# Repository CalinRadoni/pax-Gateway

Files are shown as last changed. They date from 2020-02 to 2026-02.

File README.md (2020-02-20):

# ESP32 RFM69HCW / RFM95/96/97/98(W) Gateway

The purpose of this gateway is to either:

- connect a RFM69-based network to Wi-Fi
- connect a LoRa&trade; transceiver to Wi-Fi

The gateway was designed for power efficiency without sacrificing functionality.

**Status:** (*this is work in progress !*)

## Features

- the core is a ESP32-WROOM-32x Wi-Fi+BT+BLE module
- RFM69HCW or RFM95/96/97/98(W) module
- Li-Ion / Li-Polymer battery charger
- Li-Ion / Li-Polymer backup battery with 18650 or 14500 sockets
- high efficiency synchronous buck converter
- supply voltage supervisor
- 4 LEDs for status
- humidity and temperature sensor
- placeholder for ATSHA204A, ATECC508A or ATECC608A IC
- (*optional*) boot mode selection using DTR and RTS signal

## Software

The code dedicated to this board is not yet built.

## Development Environment

Operating system is [Debian](https://www.debian.org/)

Tools:

- [KiCad EDA](http://kicad-pcb.org/)
- [Visual Studio Code](https://code.visualstudio.com/)
- [Espressif IoT Development Framework](https://github.com/espressif/esp-idf)
- [Git](https://git-scm.com/)
- [GIMP](https://www.gimp.org/)
- [Inkscape](https://inkscape.org/en/)

## Versions

### Version 1

- *Fab* files are moved to the Fab-v1 directory
- The PCBs from SeeedStudio arrived
- Most components are sourced
- I should build some boards
- I should start to write some software

## License

The software and documentation are released under the [GNU GPLv3](http://www.gnu.org/licenses/gpl-3.0.html) License. See the __LICENSE-GPLv3.txt__ file.

The hardware schematics are licensed under a [Creative Commons Attribution-ShareAlike 4.0 International License](http://creativecommons.org/licenses/by-sa/4.0/).
See the __LICENSE-CC-BY-SA-4.0.txt__ file.

## About RFM modules

### RFM69

From it's datasheet:

*The RFM69HCW is a transceiver module capable of operation over a wide frequency range, including the 315,433,868 and 915MHz license-free ISM (Industry Scientific and Medical) frequency bands.*

*All major RF communication parameters are programmable and most of them can be dynamically set. The RFM69HCW offers the unique advantage of programmable narrow-band and wide- band communication modes.*

*The RFM69HCW is optimized for low power consumption while offering high RF output power and channelized operation. Compliance ETSI and FCC regulations.*

### RFM95/96/97/98(W)

From it's datasheet:

*The RFM95/96/97/98(W) incorporates the LoRa TM spread spectrum modem which is capable of achieving significantly longer range than existing systems based on FSK or OOK modulation.*

*[...] Another benefit of the spread modulation is that each spreading factor is orthogonal - thus multiple transmitted signals can occupy the same channel without interfering. This also permits simple coexistence with existing FSK based systems.*

*Standard GFSK, FSK, OOK, and GMSK modulation is also provided to allow compatibility with existing systems or standards such as wireless MBUS and IEEE 802.15.4g.*

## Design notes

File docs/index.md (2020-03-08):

---
layout: page
title: "Documentation for pax-Gateway"
description: "pax-Gateway: Documentation about usage, hardware and software"
---

right now this page is for testing the integration with GitHub Pages

## Title 2

### Title 3

#### Title 4

text *text* **text**

* aaa
* bbb
* [pax-devices](https://github.com/CalinRadoni/pax-devices)

```c++
/**
This file is part of pax-devices (https://github.com/CalinRadoni/pax-devices)
*/

#include "freertos/FreeRTOS.h"
#include "freertos/task.h"

const char* TAG = "Init";

extern "C" {

    void app_main()
    {
        simpleOTA.CheckApplicationImage();

        esp_err_t err = board.Initialize();
        if (err != ESP_OK) {
            ESP_LOGE(TAG, "Initialization failed !");
            board.DoNothingForever();
        }

        // ... nothing more, just highlighting test

    }
}
```

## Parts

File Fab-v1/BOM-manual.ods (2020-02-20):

Reference | Value | Footprint | notes | source | variant | characteristics | manufacturer | package | part-number | Qty | 2
C1,C2,C5,C6,C22,C26,C30,C32 | 100nF | CalinGeneric:C0805HS |  |  |  | 100 nF / 50V / X7R | Samsung | 0805 | CL21B104KBCNNNC | 8 | 16
C41 | 100nF | CalinGeneric:C0805HS |  |  | Sensor | 100 nF / 50V / X7R | Samsung | 0805 | CL21B104KBCNNNC | 1 | 2
C3,C10,C20,C21,C31 | 10uF | CalinGeneric:C0805HS |  |  |  | 10 µF / 6,3 V | Samsung | 0805 | CL21B106KQQNNNE | 5 | 10
C23 | 10uF/10V/1mOhm | CalinGeneric:C0805HS |  |  |  | 10 µF / 10 V / X5R / ESR: 1 mΩ | Taiyo Yuden | 0805 | EMK212BJ106KG-T | 1 | 2
C24 | 22uF/6.3V/1mOhm | CalinGeneric:C0805HS |  |  |  | 22 µF / 6.3 V / X5R / ESR: 1 mΩ | Taiyo Yuden | 0805 | JMK212BBJ226MGHT | 1 | 2
C25 | 100pF | CalinGeneric:C0805HS |  |  |  | 100pF / 50V / X7R | Wurth Electronics | 0805 | 885012207080 | 1 | 2
D1 | LED | CalinGeneric:LED0805HS |  |  |  | Green ? Blue ? |  | 0805 |  | 1 | 2
D10-D13 | LED | CalinGeneric:LED0805HS |  |  |  | Green ? Yellow-green ? |  | 0805 |  | 4 | 8
D21 | B340AE-13 | CalinGeneric:SMA-HS |  |  |  | 3A schottky rectifier | Diodes | SMA | B340AE-13 | 1 | 2
D29 | LED Green | CalinGeneric:LED0805HS |  |  | test | Green ? ... ? |  |  |  | 1 | 2
J23 | s18650 | CalinConnectors:KEYS-1043 |  |  | 18650 |  | Keystone | * | KEYS1043 | 1 | 2
J30 | AntSMA | CalinConnectors:SMA-90 |  |  |  | RF2-49B-T-00-50-G-HDW or RF2-03E-T-00-50-G | Adam Tech | * | RF2-49B-T-00-50-G-HDW | 1 | 2
L21 | 2.2uH | CalinGeneric:ASPI-0530HI |  |  |  |  | Abracon Corporation |  | ASPI-0530HI-2R2M-T2 | 1 | 2
Q20 | IRLML2244 | CalinGeneric:SOT-23-GSD-HS |  |  |  | * | International Rectifier | SOT23-3 | IRLML2244TRPbF | 1 | 2
Q40, Q41 | BC817 | CalinGeneric:SOT-23 |  |  |  | BC817-40 | Diodes | SOT-23 | BC817-40 | 2 | 4
R1,R25,R26,R40,R41 | 10k | CalinGeneric:R0805HS |  |  |  | 10k | Vishay | 0805 | CRCW080510K0FKEA | 5 | 10
R2, R29 | 330 | CalinGeneric:R0805HS |  |  |  | 330 | Vishay | 0805 | CRCW0805330RFKTABC | 2 | 4
R3,R4,R20 | 2k2 | CalinGeneric:R0805HS |  |  |  | 2k2 | Panasonic | 0805 | ERJ-6ENF2201V | 3 | 6
R10 - R13 | 100 | CalinGeneric:R0805HS |  |  |  | 100 1% | Panasonic | 0805 | ERJ-6ENF1000V | 4 | 8
R22, R23 | 2M | CalinGeneric:R0805HS |  | Mouser |  | 2M 1% | Panasonic | 0805 | ERJ-6ENF2004V | 2 | 4
R27 | 442k 1% | CalinGeneric:R0805HS |  | Mouser |  | 442k 1% | Panasonic | 0805 | ERJ-6ENF4423V | 1 | 2
R28 | 100k 1% | CalinGeneric:R0805HS |  | Mouser |  | 100k 1% | Panasonic | 0805 | ERJ-6ENF1003V | 1 | 2
SYM10 – SYM13 | LightPipe | CalinGeneric:SLP3-xxx-150-x |  |  |  | LightPipe | BIVAR | SLP3-XXX-XXX-X | SLP3-150-150-F | 4 | 8
U1 | ESP-WROOM-32 | CalinGeneric:ESP-WROOM-32-HandSolder |  |  |  | * | Espressif | * | ESP32-WROOM-32 | 1 | 2
U20 | IRM-10-5 | CalinGeneric:IRM222A |  |  |  |  | Mean Well | 222A | IRM-10-5 | 1 | 2
U21 | MCP73832T-2ACI | CalinGeneric:SOT-23-5-HS |  |  |  |  | Microchip | SOT23-5 | MCP73832T-2ACI | 1 | 2
U22 | BD49K35 | CalinGeneric:SOT-23-HS |  |  |  |  | ROHM Semiconductor | SSOP3 (SOT23-3) | BD49K37G-TL | 1 | 2
U23 | TLV62569DBV | CalinGeneric:SOT-23-5-HS |  |  |  |  | Texas Instrumnets | SOT23-5 | TLV62569DBV | 1 | 2
U24 | TLV379IDBV | CalinGeneric:SOT-23-5-HS |  |  |  |  | Texas Instruments | SOT23-5 | TLV379IDBV | 1 | 2
U30 | RFM9x | CalinGeneric:RFM69HCW |  |  |  | * | HOPERF | * | RFM69HCW | 1 | 2
U41 | HDC1080DMB | CalinGeneric:WSON6-TI-HDC-HS |  |  | Sensor |  | Texas Instruments | WSON6 | HDC1080DMB | 1 | 2
Box |  |  |  | TME |  |  | Gainta |  | G738 or G706
J1 | ph_1x2 | CalinConnectors:Pin_Header_Straight_1x02 | DNP |  | test |  |  |  |  | 1 | 2
J2 | ph_1x2 | CalinConnectors:Pin_Header_Straight_1x02 | DNP |  | test |  |  |  |  | 1 | 2
J21 | ph_1x2 | CalinConnectors:Pin_Header_Straight_1x02 | DNP |  | test |  |  |  |  | 1 | 2
J40 | ph_1x2 | CalinConnectors:Pin_Header_Straight_1x02 |  |  |  |  |  |  |  | 1 | 2
J3 | ph_1x3 | CalinConnectors:Pin_Header_Straight_1x03_Cyan |  |  |  |  |  |  |  | 1 | 2
J4 | ph_1x4 | CalinConnectors:Pin_Header_Straight_1x04 |  |  |  |  |  |  |  | 1 | 2
J5 | ph_1x4 | CalinConnectors:Pin_Header_Straight_1x04 |  |  |  |  |  |  |  | 1 | 2
J7 | ph_1x4 | CalinConnectors:Pin_Header_Straight_1x04 | DNP |  | test |  |  |  |  | 1 | 2
J6 | ph_1x3 | CalinConnectors:Pin_Header_Straight_1x03_Yellow |  |  |  |  |  |  |  | 1 | 2
J8 | ph_1x6 | CalinConnectors:Pin_Header_Straight_1x06 |  |  |  | * | * | * | * | 1 | 2
J20 | 220V~ | CalinConnectors:THT_Pins_Big_1x3 | DNP |  | pcb |  |  |  |  | 1 | 2
J22 | s14500 | CalinConnectors:BattHolder-AA-PCB |  |  | 14500 |  |  |  |  | 1 | 2

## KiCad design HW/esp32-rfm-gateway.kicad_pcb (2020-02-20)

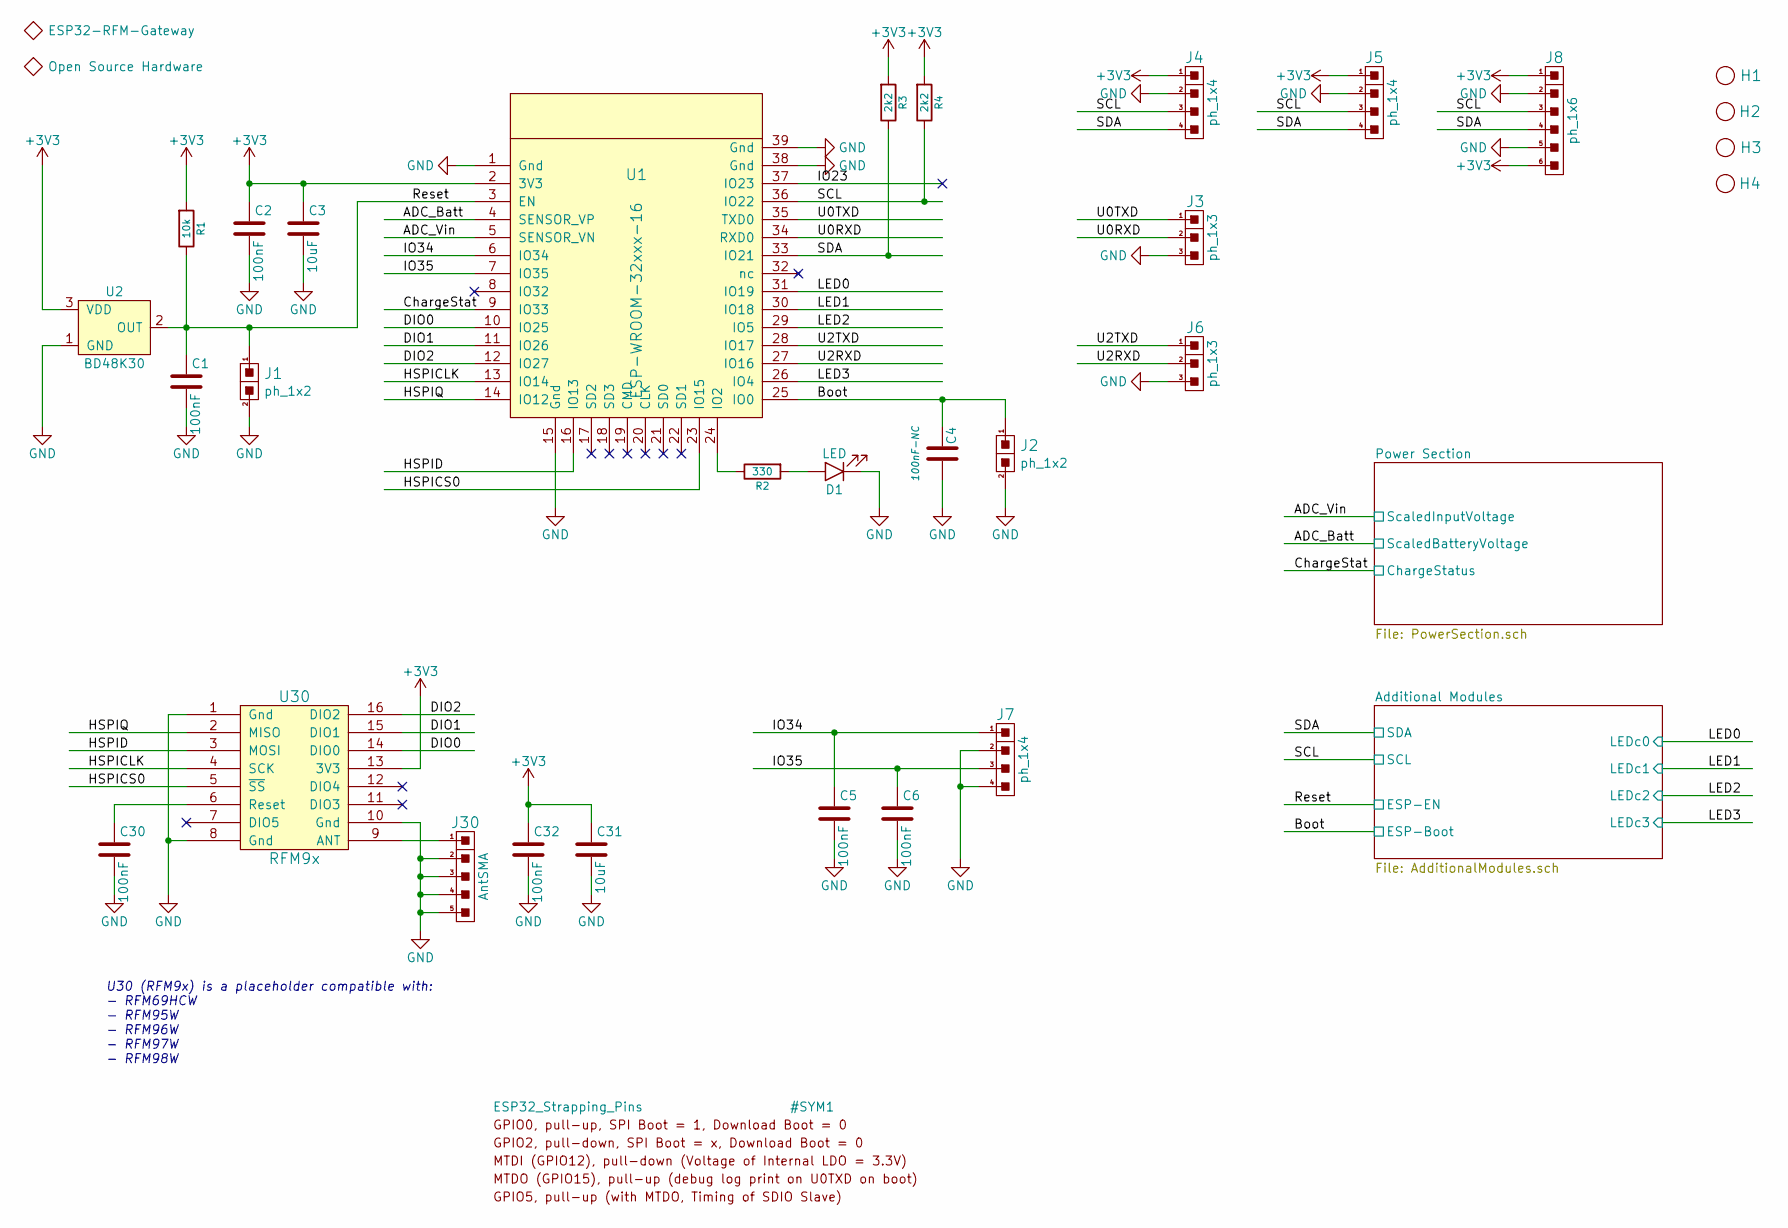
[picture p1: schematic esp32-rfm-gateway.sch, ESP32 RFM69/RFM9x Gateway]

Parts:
C1, C2, C5, C6, C30, C32: 100nF; C0805HS; part-number CL21B104KBCNNNC
C3, C31: 10uF; C0805HS; part-number CL21B106KQQNNNE
C4: 100nF-NC; C0805HS; part-number DNP
D1: LED; LED0805HS
H1, H2, H3, H4: Hole; HoleNPT-M2.5
J1, J2: ph_1x2; Pin_Header_Straight_1x02
J3: ph_1x3; Pin_Header_Straight_1x03_Cyan
J4, J5, J7: ph_1x4; Pin_Header_Straight_1x04
J6: ph_1x3; Pin_Header_Straight_1x03_Yellow
J8: ph_1x6; Pin_Header_Straight_1x06; part-number *
J30: AntSMA; SMA-90; part-number RF2-49B-T-00-50-G-HDW
R1: 10k; R0805HS; part-number CRCW080510K0FKEA
R2: 330; R0805HS; part-number CRCW0805330RFKTABC
R3, R4: 2k2; R0805HS; part-number ERJ-6ENF2201V
SYM2: Open Source Hardware; OSHW-Logo_SilkS; part-number DNP
SYM5: ESP32-RFM-Gateway; ValueAsText; part-number DNP
U1: ESP-WROOM-32xxx-16; ESP-WROOM-32-HandSolder; part-number ESP32-WROOM-32D-16
U2: BD48K30; SOT-23-HS; part-number BD48K30G-TL
U30: RFM9x; RFM69HCW; part-number RFM69HCW

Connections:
+3V3: C2.1, C3.1, C31.1, C32.1, J4.1, J5.1, J8.1, J8.6, R1.1, R3.1, R4.1, U1.2 (3V3), U2.3 (VDD), U30.13 (3V3); also elsewhere on the board
/ADC_Batt: U1.4 (SENSOR_VP); also elsewhere on the board
/ADC_Vin: U1.5 (SENSOR_VN); also elsewhere on the board
/Boot: C4.1, J2.1, U1.25 (IO0); also elsewhere on the board
/ChargeStat: U1.9 (IO33); also elsewhere on the board
/DIO0: U1.10 (IO25), U30.14 (DIO0)
/DIO1: U1.11 (IO26), U30.15 (DIO1)
/DIO2: U1.12 (IO27), U30.16 (DIO2)
/HSPICLK: U1.13 (IO14), U30.4 (SCK)
/HSPICS0: U1.23 (IO15), U30.5 (~SS)
/HSPID: U1.16 (IO13), U30.3 (MOSI)
/HSPIQ: U1.14 (IO12), U30.2 (MISO)
/IO34: C5.1, J7.1, U1.6 (IO34)
/IO35: C6.1, J7.3, U1.7 (IO35)
/LED0: U1.31 (IO19); also elsewhere on the board
/LED1: U1.30 (IO18); also elsewhere on the board
/LED2: U1.29 (IO5); also elsewhere on the board
/LED3: U1.26 (IO4); also elsewhere on the board
/Reset: C1.1, J1.1, R1.2, U1.3 (EN), U2.2 (OUT); also elsewhere on the board
/SCL: J4.3, J5.3, J8.3, R4.2, U1.36 (IO22); also elsewhere on the board
/SDA: J4.4, J5.4, J8.4, R3.2, U1.33 (IO21); also elsewhere on the board
/U0RXD: J3.2, U1.34 (RXD0)
/U0TXD: J3.1, U1.35 (TXD0)
/U2RXD: J6.2, U1.27 (IO16)
/U2TXD: J6.1, U1.28 (IO17)
GND: C1.2, C2.2, C3.2, C4.2, C5.2, C6.2, C30.2, C31.2, C32.2, D1.K, J1.2, J2.2, J3.3, J4.2, J5.2, J6.3, J7.2, J7.4, J8.2, J8.5, J30.2, J30.3, J30.4, J30.5, U1.1 (Gnd), U1.15 (Gnd), U1.38 (Gnd), U1.39 (Gnd), U2.1 (GND), U30.1 (Gnd), U30.8 (Gnd), U30.10 (Gnd); also elsewhere on the board
unnamed: C30.1, U30.6 (Reset)
unnamed: D1.A, R2.1
unnamed: J30.1, U30.9 (ANT)
unnamed: R2.2, U1.24 (IO2)

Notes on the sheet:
U30 (RFM9x) is a placeholder compatible with: - RFM69HCW - RFM95W - RFM96W - RFM97W - RFM98W

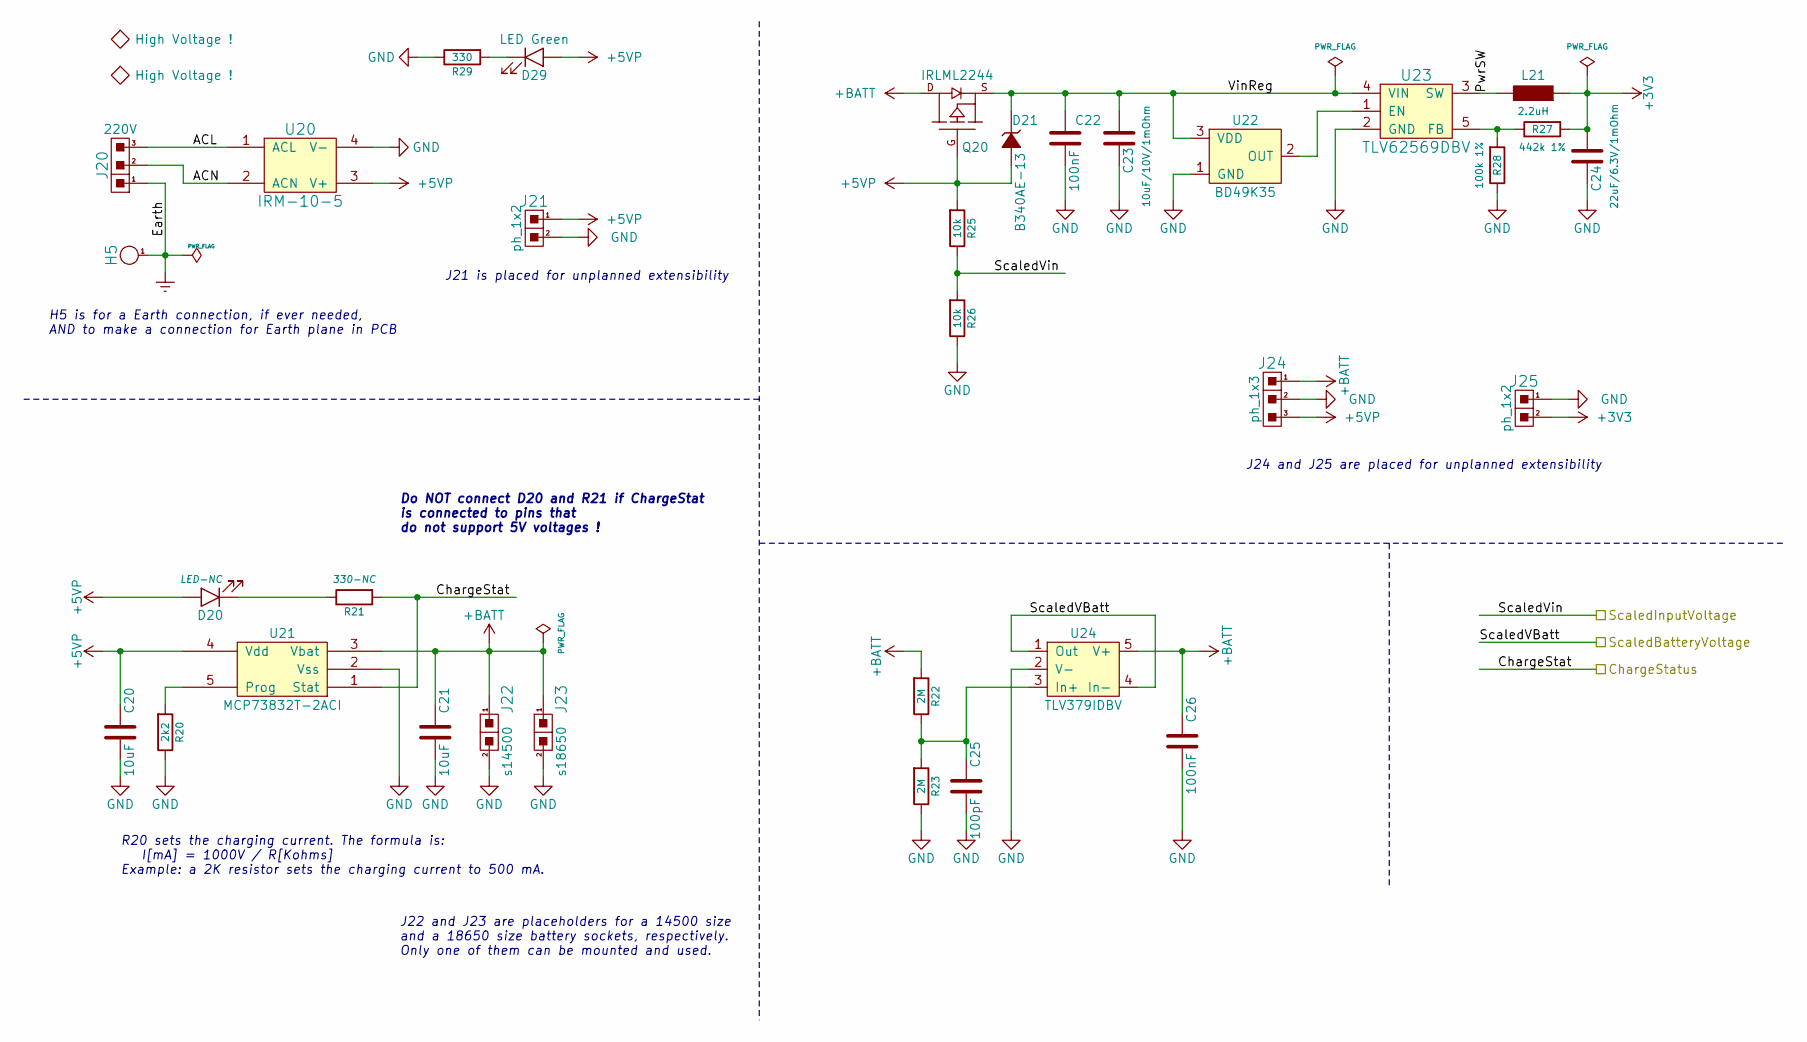
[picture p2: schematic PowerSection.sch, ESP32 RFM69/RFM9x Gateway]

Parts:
C20, C21: 10uF; C0805HS; part-number CL21B106KQQNNNE
C22, C26: 100nF; C0805HS; part-number CL21B104KBCNNNC
C23: 10uF/10V/1mOhm; C0805HS; part-number EMK212BJ106KG-T
C24: 22uF/6.3V/1mOhm; C0805HS; part-number JMK212BBJ226MGHT
C25: 100pF; C0805HS; part-number 885012207080
D20: LED-NC; LED0805HS; part-number DNP
D21: B340AE-13; SMA-HS; part-number B340AE-13
D29: LED Green; LED0805HS
H5: HolePlated; SMD_Pins_Big_1x1
J20: 220V~; THT_Pins_Big_1x3
J21: ph_1x2; Pin_Header_Straight_1x02
J22: s14500; BattHolder-AA-PCB
J23: s18650; KEYS-1043; part-number KEYS1043
J24: ph_1x3; Pin_Header_Angled_1x03
J25: ph_1x2; Pin_Header_Angled_1x02
L21: 2.2uH; ASPI-0530HI; part-number ASPI-0530HI-2R2M-T2
Q20: IRLML2244; SOT-23-GSD-HS; part-number IRLML2244TRPbF
R20: 2k2; R0805HS; part-number ERJ-6ENF2201V
R21: 330-NC; R0805HS; part-number DNP
R22, R23: 2M; R0805HS; part-number ERJ-6ENF2004V
R25, R26: 10k; R0805HS; part-number CRCW080510K0FKEA
R27: 442k 1%; R0805HS; part-number ERJ-6ENF4423V
R28: 100k 1%; R0805HS; part-number ERJ-6ENF1003V
R29: 330; R0805HS; part-number CRCW0805330RFKTABC
SYM3, SYM4: High Voltage !; Symbol_HighVoltage_SilkS; part-number DNP
U20: IRM-10-5; IRM222A; part-number IRM-10-5
U21: MCP73832T-2ACI; SOT-23-5-HS; part-number MCP73832T-2ACI
U22: BD49K35; SOT-23-HS; part-number BD49K37G-TL
U23: TLV62569DBV; SOT-23-5-HS; part-number TLV62569DBV
U24: TLV379IDBV; SOT-23-5-HS; part-number TLV379IDBV

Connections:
+3V3: C24.1, J25.2, L21.1, R27.1; also elsewhere on the board
+5VP: C20.1, D20.A, D21.2 (A), D29.A, J21.1, J24.3, Q20.G, R25.1, U20.3 (V+), U21.4 (Vdd)
+BATT: C21.1, C26.1, J22.1, J23.1, J24.1, Q20.D, R22.1, U21.3 (Vbat), U24.5 (V+)
/ADC_Batt: U24.1 (Out), U24.4 (In-); also elsewhere on the board
/ADC_Vin: R25.2, R26.1; also elsewhere on the board
/ChargeStat: R21.1, U21.1 (Stat); also elsewhere on the board
/Power Section/ACL: J20.3, U20.1 (ACL)
/Power Section/ACN: J20.2, U20.2 (ACN)
/Power Section/PwrSW: L21.2, U23.3 (SW)
/Power Section/VinReg: C22.1, C23.1, D21.1 (K), Q20.S, U22.3 (VDD), U23.4 (VIN)
Earth: H5.1, J20.1
GND: C20.2, C21.2, C22.2, C23.2, C24.2, C25.2, C26.2, J21.2, J22.2, J23.2, J24.2, J25.1, R20.2, R23.2, R26.2, R28.2, R29.2, U20.4 (V-), U21.2 (Vss), U22.1 (GND), U23.2 (GND), U24.2 (V-); also elsewhere on the board
unnamed: C25.1, R22.2, R23.1, U24.3 (In+)
unnamed: D20.K, R21.2
unnamed: D29.K, R29.1
unnamed: R20.1, U21.5 (Prog)
unnamed: R27.2, R28.1, U23.5 (FB)
unnamed: U22.2 (OUT), U23.1 (EN)

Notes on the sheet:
J24 and J25 are placed for unplanned extensibility
J21 is placed for unplanned extensibility
R20 sets the charging current. The formula is: I[mA] = 1000V / R[Kohms] Example: a 2K resistor sets the charging current to 500 mA.
J22 and J23 are placeholders for a 14500 size and a 18650 size battery sockets, respectively. Only one of them can be mounted and used.
H5 is for a Earth connection, if ever needed, AND to make a connection for Earth plane in PCB
Do NOT connect D20 and R21 if ChargeStat is connected to pins that do not support 5V voltages !

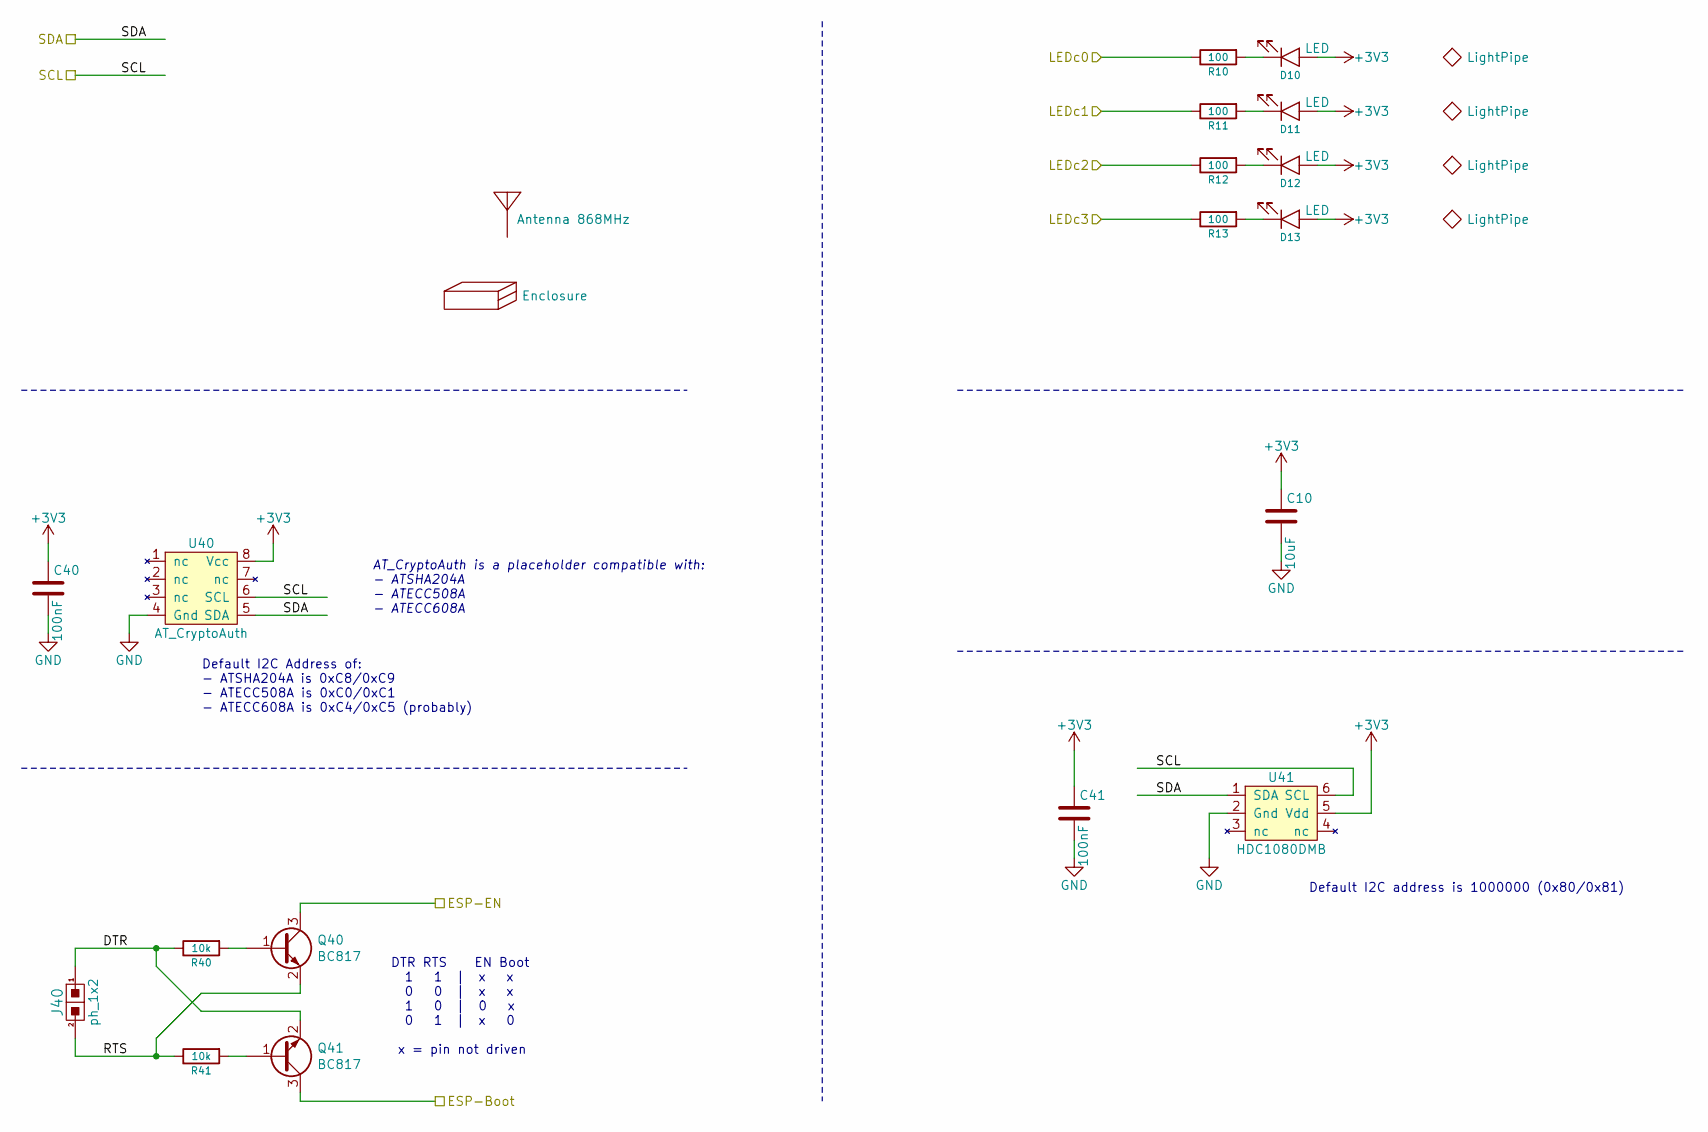
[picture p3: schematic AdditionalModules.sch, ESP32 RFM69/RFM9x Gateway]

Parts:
C10: 10uF; C0805HS; part-number CL21B106KQQNNNE
C40, C41: 100nF; C0805HS; part-number CL21B104KBCNNNC
D10, D11, D12, D13: LED; LED0805HS
J40: ph_1x2; Pin_Header_Straight_1x02
Q40, Q41: BC817; SOT-23; part-number BC817-40
R10, R11, R12, R13: 100; R0805HS; part-number ERJ-6ENF1000V
R40, R41: 10k; R0805HS; part-number CRCW080510K0FKEA
SYM6: Antenna 868MHz; VirtualFootprint; part-number 868M-ANT410
SYM9: Enclosure; VirtualFootprint; part-number Gainta G706
SYM10, SYM11, SYM12, SYM13: LightPipe; SLP3-xxx-150-x; part-number SLP3-150-150-F
U40: AT_CryptoAuth; SOIC-8-HS; part-number ATSHA204A/ATECC508A/ATECC608A-SSHDA
U41: HDC1080DMB; WSON6-TI-HDC-HS; part-number HDC1080DMB

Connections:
+3V3: C10.1, C40.1, C41.1, D10.A, D11.A, D12.A, D13.A, U40.8 (Vcc), U41.5 (Vdd); also elsewhere on the board
/Additional Modules/DTR: J40.1, Q41.2 (E), R40.2
/Additional Modules/RTS: J40.2, Q40.2 (E), R41.2
/Boot: Q41.3 (C); also elsewhere on the board
/LED0: R10.2; also elsewhere on the board
/LED1: R11.2; also elsewhere on the board
/LED2: R12.2; also elsewhere on the board
/LED3: R13.2; also elsewhere on the board
/Reset: Q40.3 (C); also elsewhere on the board
/SCL: U40.6 (SCL), U41.6 (SCL); also elsewhere on the board
/SDA: U40.5 (SDA), U41.1 (SDA); also elsewhere on the board
GND: C10.2, C40.2, C41.2, U40.4 (Gnd), U41.2 (Gnd); also elsewhere on the board
unnamed: D10.K, R10.1
unnamed: D11.K, R11.1
unnamed: D12.K, R12.1
unnamed: D13.K, R13.1
unnamed: Q40.1 (B), R40.1
unnamed: Q41.1 (B), R41.1

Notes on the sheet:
AT_CryptoAuth is a placeholder compatible with: - ATSHA204A - ATECC508A - ATECC608A
DTR RTS EN Boot 1 1 | x x 0 0 | x x 1 0 | 0 x 0 1 | x 0 x = pin not driven
Default I2C Address of: - ATSHA204A is 0xC8/0xC9 - ATECC508A is 0xC0/0xC1 - ATECC608A is 0xC4/0xC5 (probably)
Default I2C address is 1000000 (0x80/0x81)

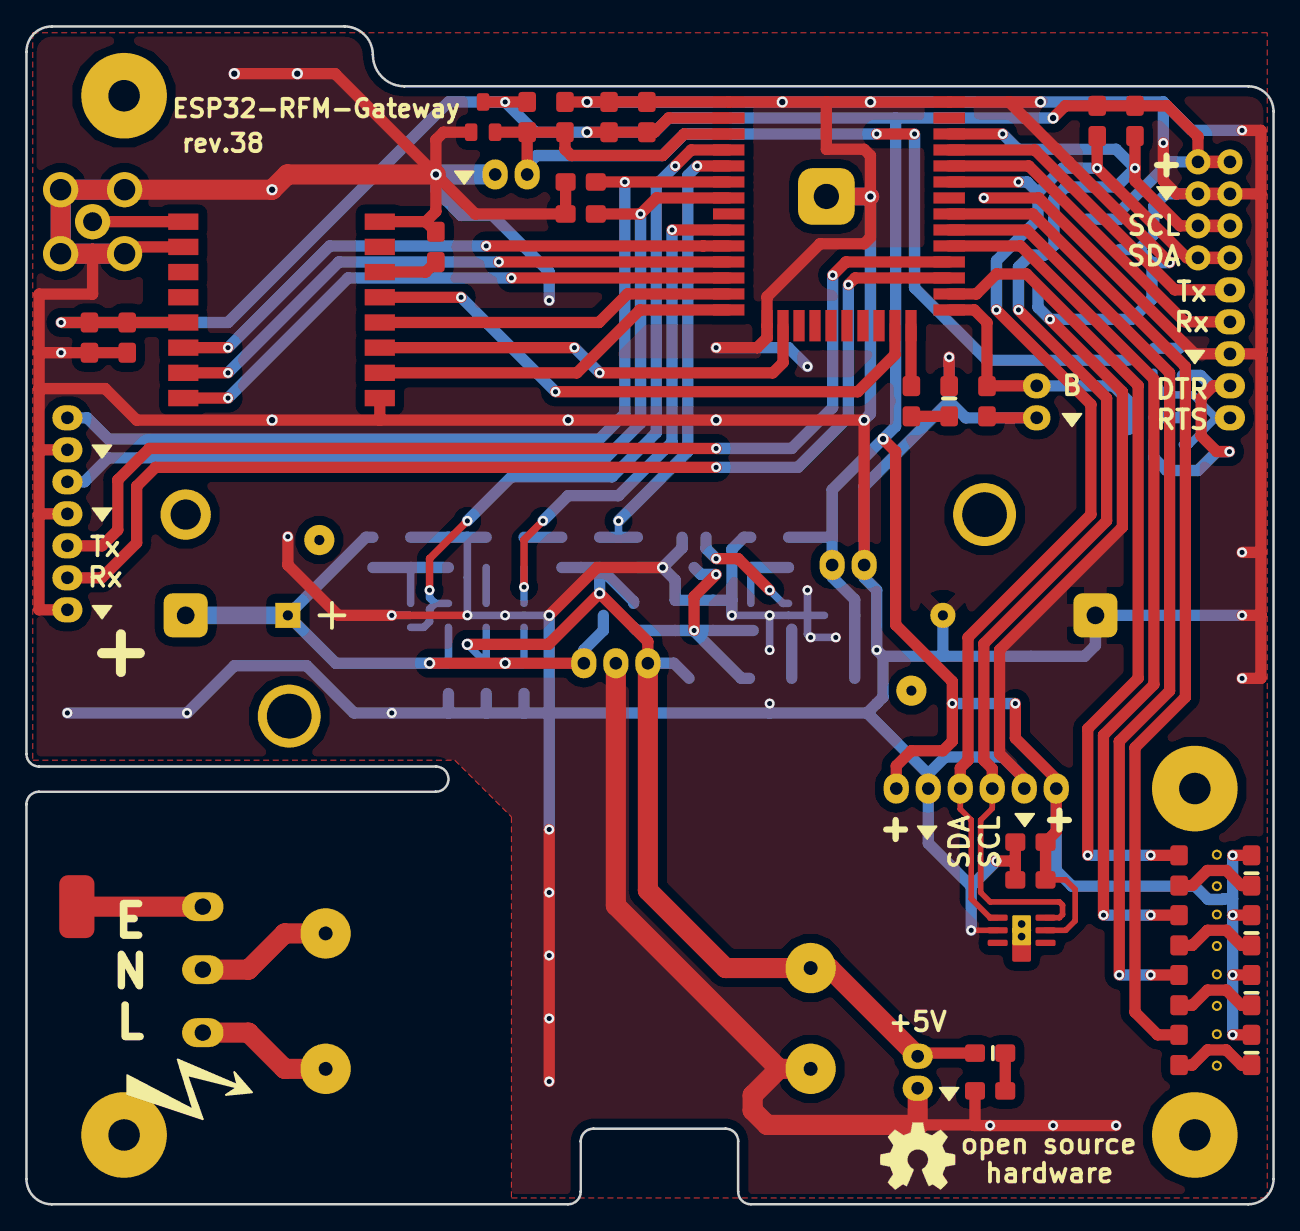
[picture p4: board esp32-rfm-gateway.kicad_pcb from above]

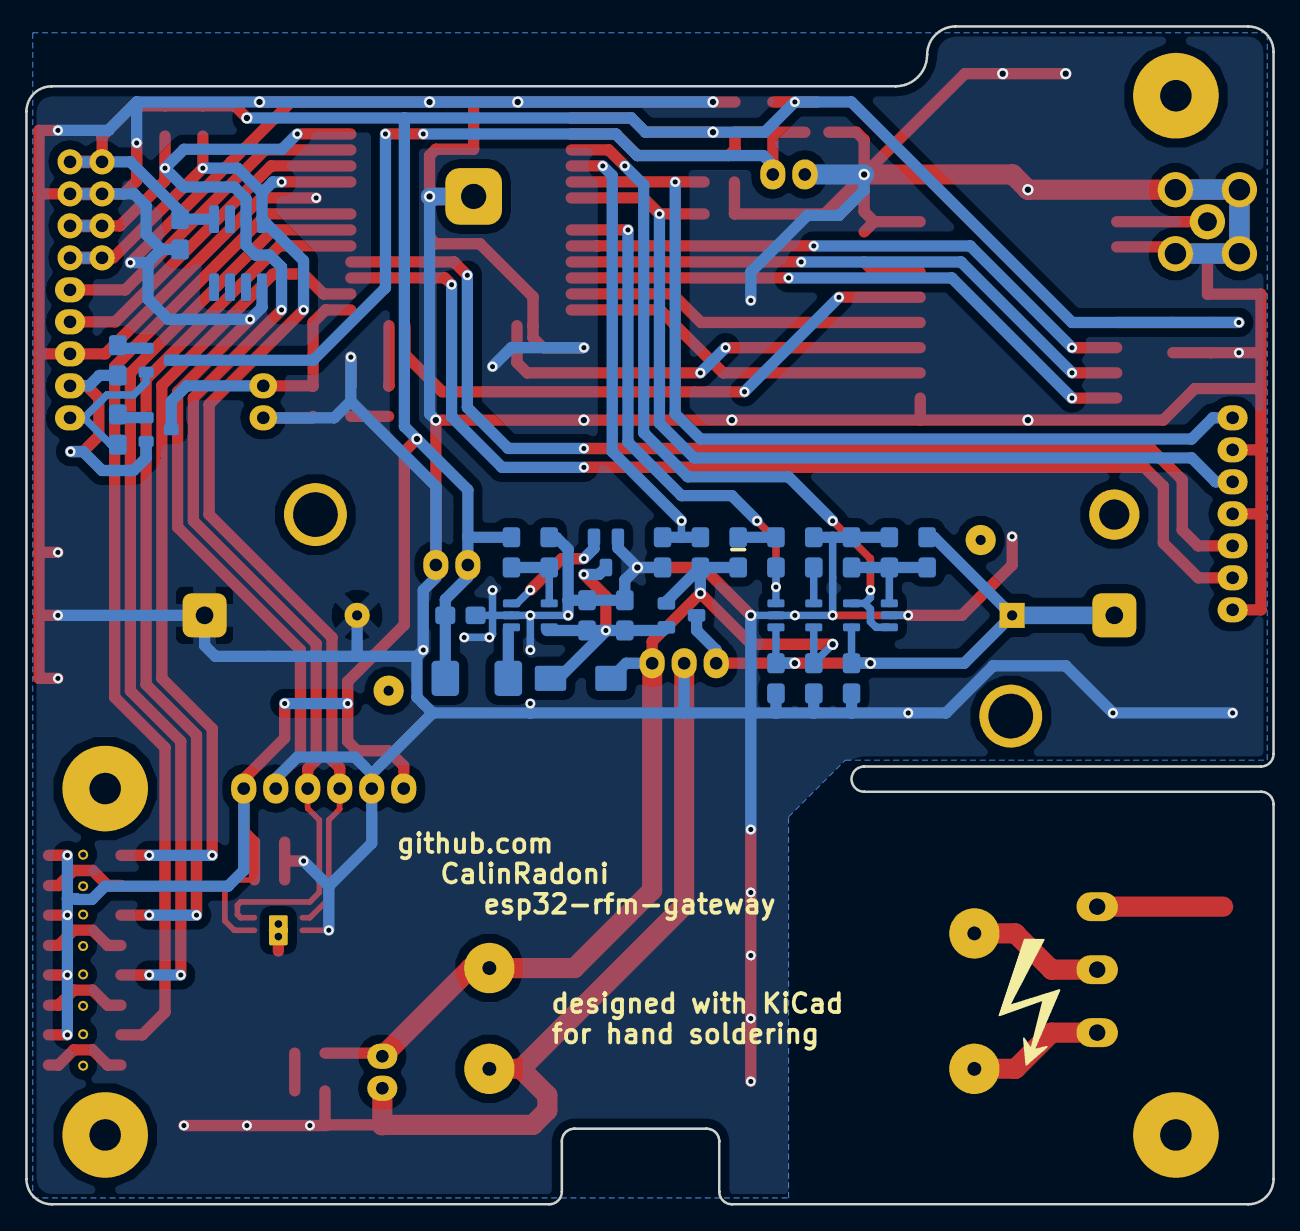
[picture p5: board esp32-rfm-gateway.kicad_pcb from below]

Board: 2 copper layers, 99.0 x 93.5 mm, 91 parts (32 on the bottom side), 51 nets.

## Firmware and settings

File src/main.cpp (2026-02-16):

#include "paxGW.h"
#include "paxGWConfig.h"

paxGW_Board board;
paxGW_Config config;

uint32_t restartRequired = 0;

void printLocalTime()
{
    struct tm timeInfo;
    if (!getLocalTime(&timeInfo)) {
        log_e("Failed to obtain time");
        // restartRequired = 1000;
        return;
    }
    Serial.println(&timeInfo, "%Y.%B.%d %H:%M:%S");
    log_i("%d.%02d.%02d %02d:%02d:%02d",
        1900 + timeInfo.tm_year, 1 + timeInfo.tm_mon, timeInfo.tm_mday,
        timeInfo.tm_hour, timeInfo.tm_min, timeInfo.tm_sec);
}

void setup()
{
    Serial.begin(115200);

    board.Initialize(&config);

    if (config.srvNTP.length() > 0) {
        configTzTime(config.timeZone.c_str(), config.srvNTP.c_str());
    } else {
        log_e("NTP synchronization not configured.");
    }
    printLocalTime();

#ifdef SSD1306_DISPLAY
    board.ShowStatus();
#endif

    restartRequired = 0;
}

void loop()
{
    board.CheckQueue();

    board.CheckConnection(true);
    
    // reset here if requested
    if (restartRequired > 0) {
        board.ResetBoard(restartRequired);
    }

    yield();
}

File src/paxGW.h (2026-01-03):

#ifndef paxGW_H
#define paxGW_H

#include <Arduino.h>
#include <SPI.h>

#include "board.h"
#include "paxGWConfig.h"

#ifdef Radio_RFM69
#include <RHReliableDatagram.h>
#include <RH_RF69.h>
#endif

#ifdef SSD1306_DISPLAY
#include "Display_SSD1306.h"
#endif

/*
pax-GW (esp32-rfm-gateway)

ESP-WROOM-32xxx-16 connections
SDA = IO21 (pin 33) with 2k2 pull-up
SCL = IO22 (pin 36) with 2k2 pull-up
SDA and SCL goes to:
- J4, J5, J8
- HDC1080DMB, if installed, address 0x80/0x81
- CryptoAuth chip, if installed
    - ATSHA204A, address 0xC8/0xC9
    - ATECC508A, address 0xC0/0xC1
    - ATECC608A, address 0xC4/0xC5 (probably))

U0RXD and U0TXD = pins 34 and 35 = J3
U0RXD and U0TXD = pins 27 and 28 = J6

LED0 = IO19 (pin 31) with 100 ohms to 3V3
LED1 = IO18 (pin 30) with 100 ohms to 3V3
LED2 = IO5  (pin 29) with 100 ohms to 3V3
LED3 = IO4  (pin 26) with 100 ohms to 3V3

On board LED on IO2 with 330 ohms to ground

HSPICS0 = IO15 (pin 23) = radio -SS
HSPID   = IO13 (pin 16) = radio MOSI
HSPIQ   = IO12 (pin 14) = radio MISO
HSPICLK = IO14 (pin 13) = radio SCK

DIO0 = IO25 (pin 10) = radio DIO0
DIO1 = IO26 (pin 11) = radio DIO1
DIO2 = IO27 (pin 12) = radio DIO2

ChargeStat = IO33 (pin 9) = STAT pin of the MCP73832T-2ACI
ADC_Batt = Sensor_VP (pin 4) = half the battery voltage
ADC_Vin = Sensor_VN (pin 5 ESP-WROOM-32) = half the voltage of the 5V power source

IO34 (pin 6) with 100nF to ground goes to J7
IO35 (pin 7) with 100nF to ground goes to J7
*/

class paxGW_Board : public Board
{
public:
    paxGW_Board(void);
    virtual ~paxGW_Board();

    virtual bool Init_level0(void);
    virtual bool Init_level1(void);
    virtual bool Init_level2(void);
    virtual bool Init_level3(void);

    virtual void CustomReset(void);

    uint16_t GetVIn(void);
    uint16_t GetVBatt(void);
    bool IsCharging(void);

    /**
     * 0 - 3 for LED0 - LED3
     * any other value controls the onboard LED
     */
    void SetLED(uint8_t, bool);

#ifdef SSD1306_DISPLAY
    Display_SSD1306 display;
#endif

    void ShowStatus(void);

#ifdef Radio_RFM69
    RHReliableDatagram *radioManager;
#endif

protected:
    void InitGPIO(void);

    bool InitADC(void);

    SPIClass *hspi;
    bool InitHSPI(void);
    void CleanupHSPI(void);

#ifdef Radio_RFM69
    unsigned char radio_server_address;
    bool CreateRadio(void);
    bool InitializeRadio(void);
    void CleanupRadio(void);
#endif
};

#endif

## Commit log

2020-02-20 Reinitialization after splitting from pax-devices repository
    [AdditionalModules.sch, BOM-manual.ods, PowerSection.sch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]
2022-02-09 Begin of Arduino-based software development
2025-12-30 Migration to ESP32Board library
    [partitions4M_1600_832_nk.csv]
2025-12-30 KiCad project version update
2025-12-31 Squashed 'lib/RadioHead/' content from commit c286123
    git-subtree-dir: lib/RadioHead
    git-subtree-split: c286123546244e10dad7e764f3a2890453917c29
    [project.cfg]
2026-01-01 Added basic support for Monochrome OLEDs based on SSD1306 drivers
2026-02-08 Squashed 'lib/ESP32-BoardManager/' content from commit 4ce4ebc
    git-subtree-dir: lib/ESP32-BoardManager
    git-subtree-split: 4ce4ebc6aa99f4b98f319627b9c98a9f08f116c9
    [partitions4M_1600_760_nk.csv]
2026-02-08 Add the ESP32-BoardManager library
2026-02-09 Get rid of hardcoded WIFI_STA_DEF and WIFI_AP_DEF
    const char *Default_STA_Key = "WIFI_STA_DEF";
    const char *Default_AP_Key = "WIFI_AP_DEF";
    These should have been read from esp-idf implementation but they are not exposed in the public API.
    Current implementation keeps track of default netif(s) and do not uses `ifkey` dependent functions.
2026-02-09 Squashed 'lib/ESP32-BoardManager/' changes from 4ce4ebc..30d52d2
    30d52d2 Update documentation
    0b1cf77 Put the incomplete code for DHCPv4 Captive portal behind a #define
    b499a9e Get rid of hardcoded WIFI_STA_DEF and WIFI_AP_DEF
    3ca89cb Use uint32_t for IPv4 addresses
    98f2d09 Add the ESP32-BoardManager library
    git-subtree-split: 30d52d2f2ee18117cf19dff694d86027e4fcddcc
    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
2026-02-16 Working web settings
    [partitions4M_1600_760_nk.csv, partitions4M_1600_832_nk.csv]
